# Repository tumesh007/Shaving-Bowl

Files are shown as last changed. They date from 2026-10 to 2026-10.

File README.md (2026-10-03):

# Compact Travel Shaving Bowl

This is a fresh, open-bowl design built around a seeded mathematical height field. It contains a rounded shaving bowl, an integrated side grip, an angled open razor cradle, a centered enclosed DE-blade compartment, and a separately printable sliding drawer. **There is no lid.**

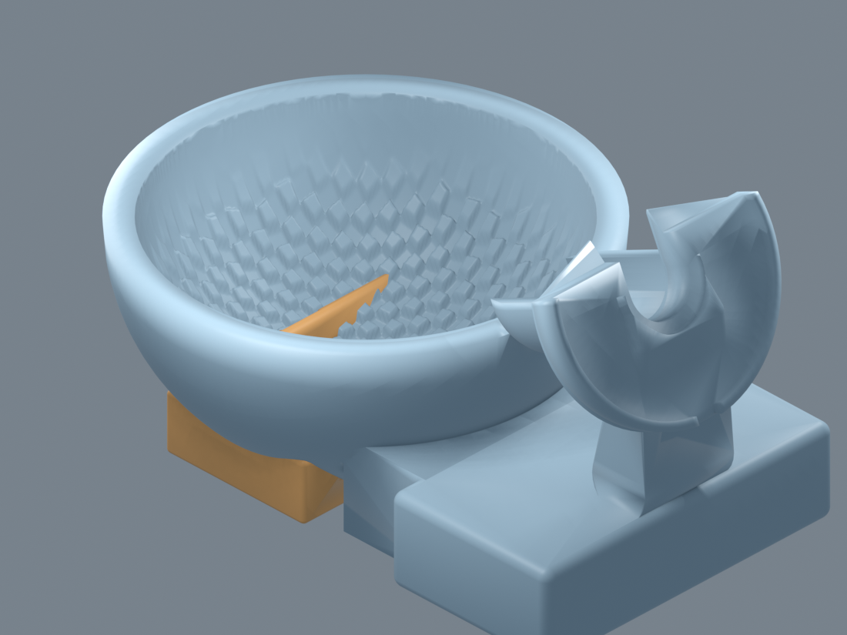
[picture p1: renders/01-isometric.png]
Isometric view of the bowl and integrated razor dock


See the [`renders/`](renders/) gallery for top, side, bottom, texture close-up, section views, and drawer/razor previews, including [`14-head-rest-closeup.png`](renders/14-head-rest-closeup.png) and [`15-name-emboss-closeup.png`](renders/15-name-emboss-closeup.png). Adjustable dimensions and texture controls are listed in [`PARAMETERS.md`](PARAMETERS.md).

## Files

- `travel_shaving_bowl.scad` — parametric source and selectable test/view modes.
- `travel_shaving_bowl.stl` — bowl/body with integrated handle, dock, and empty blade vault; drawer is excluded.
- `blade_drawer.stl` — separate captive sliding drawer with pull tab, passive detent bumps, and end-stop tabs.
- `texture_test_coupon.stl` — 40 × 40 mm terrain and diamond-pattern coupon.
- `razor_dock_test.stl` — cradle and half-round head-shelf samples for 8, 10, 12, and 15 mm handles, spaced 54 mm apart.
- `blade_storage_test.stl` — drawer samples with 1, 3, and 5 dummy blades.
- `emboss_test.stl` — curved exterior-wall patch for checking the raised name before printing the full bowl.
- `fonts/Pacifico-Regular.ttf` and `fonts/OFL.txt` — bundled Pacifico font and SIL Open Font License.
- `renders/` — isometric, orthographic, section, close-up, storage, shelf, and name previews.

## Exporting

Open the project with OpenSCAD 2021.01 or newer. `preview_mode=true` keeps interactive previews lighter. Set it to `false` for the finer production mesh. With Flatpak OpenSCAD:

```sh
flatpak run org.openscad.OpenSCAD -D 'preview_mode=false' -D 'part="bowl"' -o travel_shaving_bowl.stl travel_shaving_bowl.scad
flatpak run org.openscad.OpenSCAD -D 'preview_mode=false' -D 'part="blade_drawer"' -o blade_drawer.stl travel_shaving_bowl.scad
flatpak run org.openscad.OpenSCAD -D 'preview_mode=false' -D 'part="texture_test"' -o texture_test_coupon.stl travel_shaving_bowl.scad
flatpak run org.openscad.OpenSCAD -D 'preview_mode=false' -D 'part="razor_dock_test"' -o razor_dock_test.stl travel_shaving_bowl.scad
flatpak run org.openscad.OpenSCAD -D 'preview_mode=false' -D 'part="blade_storage_test"' -o blade_storage_test.stl travel_shaving_bowl.scad
flatpak run org.openscad.OpenSCAD -D 'preview_mode=false' -D 'part="emboss_test"' -o emboss_test.stl travel_shaving_bowl.scad
```

The top-level `part` selector supports `assembly`, `bowl`, `bowl_shell`, `blade_drawer`, `texture_test`, `razor_dock_test`, `blade_storage_test`, and `emboss_test`. Use `part="assembly"` for inspection only; export the body and drawer separately. `render_mode` supports `top`, `side`, `bottom`, `texture_closeup`, `texture_section`, `handle_section`, `blade_section`, `razor_parked`, and `blades_inside`. For example:

```sh
flatpak run org.openscad.OpenSCAD -D 'render_mode="blade_section"' -o renders/blade-section.png travel_shaving_bowl.scad
flatpak run org.openscad.OpenSCAD -D 'render_mode="blades_inside"' -o renders/blades-inside.png travel_shaving_bowl.scad
```

## Design notes

- The inside and outside bowl profiles are rounded and near-hemispherical, with a stable 45-degree conical base footprint ($r \ge 20$ mm at $z = 0.3$ mm) and a minimum 3.5 mm center floor. Nominal bowl dimensions are `bowl_outer_diameter = 84` mm, `bowl_inner_diameter = 73.7` mm, and `bowl_height = 38.5` mm.
- The lather surface uses a dense, staggered 45-degree diamond/drum pattern (`diamond_scale = 0.4`, giving 3.2 × 2.0 mm diamonds with 0.8 mm gaps) with softened ridges, shallow broad seeded undulations, and subdued connecting channels. Its outer 5.5 mm fades smoothly into the bowl wall; the relief is limited to about 4.5 mm peak-to-valley rather than deep, uneven craters.
- The razor cradle is open upward, fits the target 8–15 mm handle range, includes rounded retaining bumps and through-drainage ports, and does not drain into blade storage. Handles up to 11.6 mm seat freely; 12-15 mm handles press against the retention bumps. A vertical elevation `dock_raise = 8` mm lifts the entire dock, retention bumps, head shelf, and mount posts above the handle shell. A half-round head shelf supports the assembled razor head, with a U-shaped neck slot, curved-edge retention lip, and drain gap.
- Mostly self-supporting design (`overhang_safe = true`); remaining overhangs: 27 mm flat drawer ceiling bridge (1,287 mm²), dock underside (231 mm²), shelf tip (156 mm²). Features include:
  - 45° conical base transition meeting the sphere tangentially, providing a wide $\ge 21.5$ mm bed footprint that eliminates spherical bottom overhangs.
  - Dock support gussets (`gusset_start = 2.0`, `gusset_drop = 12.0`) bracing the cradle and mount posts down to the handle.
  - 45° inverted conical under-plate (`head_rest_lower_plate()`) with a 0.5 mm perimeter inset supporting the head shelf without non-manifold edge artifacts.
  - 45° pitched ceiling on the handle grip cutout and a 54° lower handle junction taper directly to the base.
  - The only overhang $> 500$ mm² is the straight 27 mm drawer vault ceiling bridge at $z \approx 10.7$ mm ($1,286.64$ mm²), which prints cleanly without supports via standard straight bridging.
- Razor head-rest parameters: `head_rest_radius=24`, `head_rest_thickness=3.5`, `head_rest_rim_height=1.6`, `head_rest_rim_width=1.6`, `head_rest_gap=3`, `head_rest_flat_edge=6`, `neck_slot_radius=6.5`, and `head_rest_drain_gap=5` (all dimensions in mm).
- `razor_dock_test.stl` includes the shelf, with its 8, 10, 12, and 15 mm dock samples spaced 54 mm apart.
- Print razor_dock_test with your real razor first; adjust head_rest_gap and neck_slot_radius to your razor's neck.
- A raised two-line name is embossed on the exterior wall opposite the handle. The bundled `fonts/Pacifico-Regular.ttf` is from Google Fonts' Pacifico family and is distributed under the SIL Open Font License in `fonts/OFL.txt`.
- Emboss parameters: `emboss_enabled`, `emboss_line1`, `emboss_line2`, `emboss_bold`, `emboss_font`, `emboss_width1`, `emboss_width2`, `emboss_line_gap`, `emboss_z`, `emboss_height`, `emboss_sink`, and `emboss_max_half_width`.
- To change the font edit `emboss_font`; the bundled Pacifico font is referenced by `use <fonts/Pacifico-Regular.ttf>` in the OpenSCAD source.
- Print the emboss_test patch first. With a 0.4 mm nozzle, keep the letter strokes at 0.8 mm or wider. `emboss_bold = 0.15` bolds the text via a 2D offset after resizing, bringing 98.27% of the line-2 stroke area above 0.8 mm while preserving full text wording.
- The blade vault and drawer are centered across the handle's middle plane, kept below the upper/lower handle attachment pads, and separated from the wet bowl and dock. The shorter vault keeps the drawer and handle balanced while preserving its front pull access. Its enlarged drawer is sized to hold an entire tuck of blades (up to 54 × 28 × 10 mm). It has adjustable per-side clearance, integral flexible detent tongues and bumps, matching body recesses, stop tabs, and a compact pull tab. Squeeze the stop tabs to remove the drawer deliberately.
- The design targets upright FDM printing with a 0.4 mm nozzle. Inspect the sections and test coupons, then physically validate wall strength, fit, washability, and drawer retention before travel use.

## Mesh verification

The production body, separate drawer, three functional test meshes, and emboss
patch were exported with OpenSCAD. `travel_shaving_bowl.stl` and
`emboss_test.stl` are watertight single-component meshes; the dock test has
four watertight, separated samples. Trimesh reports all exported meshes
watertight. This confirms mesh closure, not real-world print strength, fit, or
waterproofness. Print and physically test before travel use.

## Limitations

The razor and blades shown in preview modes are illustrative solids, not part of the production bowl STL. The model does not guarantee lather performance, razor compatibility beyond the nominal diameter range, waterproofness after printing, or blade safety. Print and test before use.

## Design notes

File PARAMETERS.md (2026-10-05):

# Parameter Reference

The canonical model and all selectable test parts are in
[`travel_shaving_bowl.scad`](travel_shaving_bowl.scad). Dimensions are in
millimetres. Edit the values near the top of that file or pass OpenSCAD `-D`
overrides when exporting.

## Bowl

| Parameter | Default | Purpose |
| --- | ---: | --- |
| `bowl_outer_diameter` | 84 | Rounded outside diameter |
| `bowl_inner_diameter` | 73.7 | Inside diameter and texture boundary |
| `bowl_height` | 38.5 | Rim height from the stable base (stays $\ge \text{inner\_radius} + 1.5$ mm) |
| `base_thickness` | 3.5 | Minimum floor thickness at the center |

The inside and outside curves are generated as near-hemispherical profiles
with a flat foot. The textured floor follows the spherical interior instead
of placing a flat plate at the bottom. `wall_thickness`, `rim_width`, and
`complete_width_with_handle` remain as design-reference values in the source;
the current profile is controlled by the inside/outside diameters and does
not use those three parameters as direct geometry inputs.

## Lather texture

| Parameter | Default | Purpose |
| --- | ---: | --- |
| `preview_mode` | `true` | Faster, coarser interactive model |
| `preview_texture_resolution` | 0.6 | Preview height-field grid spacing |
| `export_texture_resolution` | 0.25 | STL height-field grid spacing (rule: $\le$ (`diamond_width` + `diamond_spacing`) / 10) |
| `texture_seed` | 4217 | Repeatable deterministic feature layout |
| `diamond_scale` | 0.4 | Uniform scale factor: 1.0 = v4 size (8 × 5 mm); smaller = denser pattern |
| `diamond_length` | 8 × `diamond_scale` | Rhombus pitch along the long axis |
| `diamond_width` | 5 × `diamond_scale` | Rhombus pitch along the short axis |
| `diamond_spacing` | max(0.8, 2 × `diamond_scale`) | Gap between repeated rhombi (≥ 0.8 mm for a 0.4 mm nozzle) |
| `diamond_ridge_height` | 1.15 | Raised drum-feature amplitude |
| `diamond_channel_depth` | 0.65 | Recessed channel amplitude |
| `diamond_height_variation` | 0.04 | Small seeded feature variation |
| `hill_max_height` | 1.3 | Positive height-field clamp |
| `valley_min_height` | -3.2 | Negative height-field clamp |
| `macro_hill_scale` | 0.35 | Broad-hill contribution |
| `macro_valley_scale` | 0.45 | Broad-valley contribution |
| `major_groove_scale` | 0.4 | Sparse broad-groove contribution |
| `outer_smooth_width` | 5.5 | Texture fade into the wall |

### Diamond scale reference

| `diamond_scale` | Diamond size (mm) | Spacing (mm) | Approx. count (r < 30 mm) | Recommended `export_texture_resolution` |
| ---: | ---: | ---: | ---: | ---: |
| 0.5 | 4.0 × 2.5 | 1.0 | ~320 | 0.35 |
| 0.4 | 3.2 × 2.0 | 0.8 | ~500 | 0.25 |
| 0.375 | 3.0 × 1.875 | 0.8 | ~570 | 0.25 |

The softened staggered rhombus field is the primary texture. Low-amplitude
seeded terrain blends into the diamonds without forming isolated deep craters.

## Handle and razor dock

| Parameter | Default | Purpose |
| --- | ---: | --- |
| `handle_width` | 20 | Grip width |
| `handle_height` | 40 | Grip height |
| `handle_projection` | 22 | Handle projection from the bowl |
| `handle_fillet` | 4 | Rounded grip edge radius |
| `razor_dock_angle` | 25 | Dock inclination in degrees |
| `razor_handle_min_diameter` | 8 | Smallest target razor handle |
| `razor_handle_max_diameter` | 15 | Largest target razor handle |
| `razor_handle_clearance` | 1.0 | Cradle fit allowance |
| `razor_dock_wall` | 3.0 | Cradle wall thickness |
| `dock_raise` | 8 | Vertical dock elevation above rim reference level |
| `overhang_safe` | `true` | Enable 45-degree self-supporting geometry (conical base, gussets, pitched cutouts) |
| `gusset_start` | 2.0 | Dock support gusset offset from cradle mount post |
| `gusset_drop` | 12.0 | Vertical drop distance for 45-degree cradle support gussets down to handle |

## Razor head rest

| Parameter | Default | Purpose |
| --- | ---: | --- |
| `head_rest_radius` | 24 | Half-round support plate radius |
| `head_rest_thickness` | 3.5 | Plate thickness |
| `head_rest_rim_height` | 1.6 | Lip height around perimeter |
| `head_rest_rim_width` | 1.6 | Lip width around perimeter |
| `head_rest_gap` | 3 | Gap between dock top and shelf bottom |
| `neck_slot_radius` | 6.5 | U-shaped neck slot radius |
| `head_rest_flat_edge` | 6 | Offset for straight edge flat cut |
| `head_rest_drain_gap` | 5 | Through-drainage cutout width |

## Blade drawer

| Parameter | Default | Purpose |
| --- | ---: | --- |
| `de_blade_length` | 56 | Standard tuck length (adjust for drawer size) |
| `de_blade_width` | 28 | Standard tuck width |
| `de_blade_thickness` | 0.25 | Single-blade thickness |
| `blade_clearance` | 0.5 | Blade fit allowance |
| `blade_storage_count` | 5 | Preview stack capacity |
| `drawer_wall` | 1.2 | Drawer wall thickness |
| `drawer_clearance` | 0.4 | Sliding clearance per mating side |
| `drawer_open_travel` | 11.9 | Maximum captive travel |
| `drawer_pull_width` | 12 | Pull-tab width |
| `drawer_pull_height` | 5 | Pull-tab height |
| `drawer_pull_projection` | 4 | Pull-tab projection |
| `detent_bump_radius` | 0.65 | Passive detent bump size |
| `detent_flexure_length` | 8 | Integral detent flexure length |
| `detent_flexure_thickness` | 1.2 | Integral detent flexure thickness |
| `drawer_endstop_overlap` | 1.0 | Captive stop-tab overlap |

The vault and tray are centered across the handle's middle plane. The bowl,
drawer, and razor cradle are distinct/dry and wet regions; there is no spring,
magnet, or lid.

## Embossed name

| Parameter | Default | Purpose |
| --- | ---: | --- |
| `emboss_enabled` | `true` | Enable raised lettering on bowl wall |
| `emboss_line1` | "Tumesh's" | Top text line |
| `emboss_line2` | "Travel Shaving Bowl" | Bottom text line |
| `emboss_bold` | 0.15 | 2D offset applied after resize to ensure stroke >= 0.8 mm |
| `emboss_font` | "Pacifico" | Font family name (requires bundled TTF) |
| `emboss_width1` | 34 | Target width for line 1 |
| `emboss_width2` | 48 | Target width for line 2 |
| `emboss_line_gap` | 10 | Vertical line spacing center-to-center |
| `emboss_z` | 22 | Vertical center elevation of text block |
| `emboss_height` | 0.8 | Outward emboss projection height |
| `emboss_sink` | 0.4 | Inward penetration into bowl wall |
| `emboss_max_half_width` | 25 | Maximum lateral half-width clamp |

## Output selectors

Set `part` to one of:

- `assembly` — preview body and separate drawer together
- `bowl` — production body
- `bowl_shell` — bowl-only geometry diagnostic
- `blade_drawer` — separate printable tray
- `texture_test`
- `razor_dock_test`
- `blade_storage_test`
- `emboss_test` — exterior-wall patch for checking raised lettering

Set `preview_mode=false` for finer STL exports. See the README for complete
Flatpak OpenSCAD export commands.

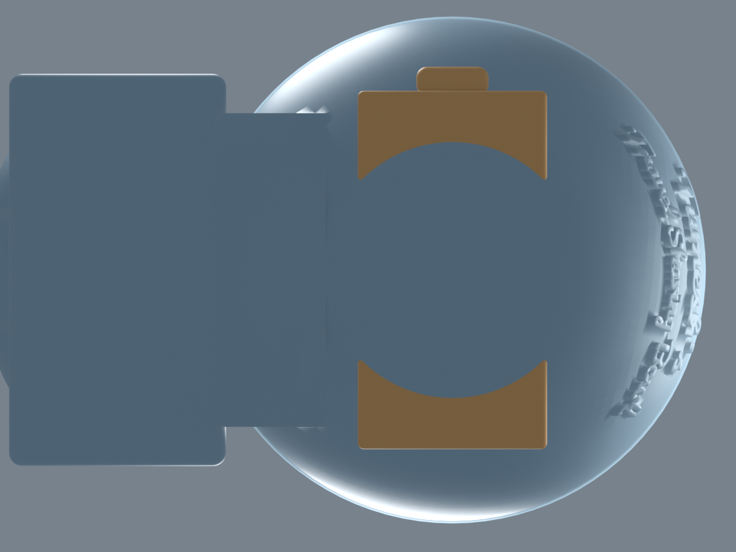
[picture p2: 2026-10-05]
renders/04-bottom.png

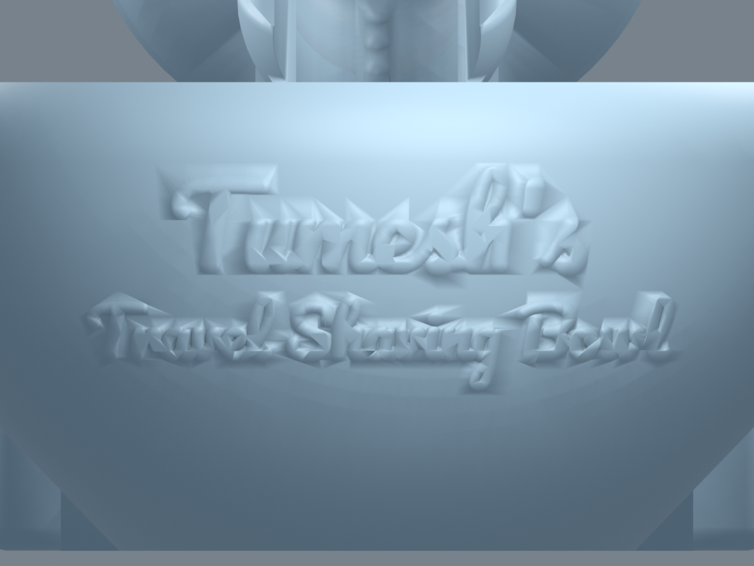
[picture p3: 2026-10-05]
renders/15-name-emboss-closeup.png

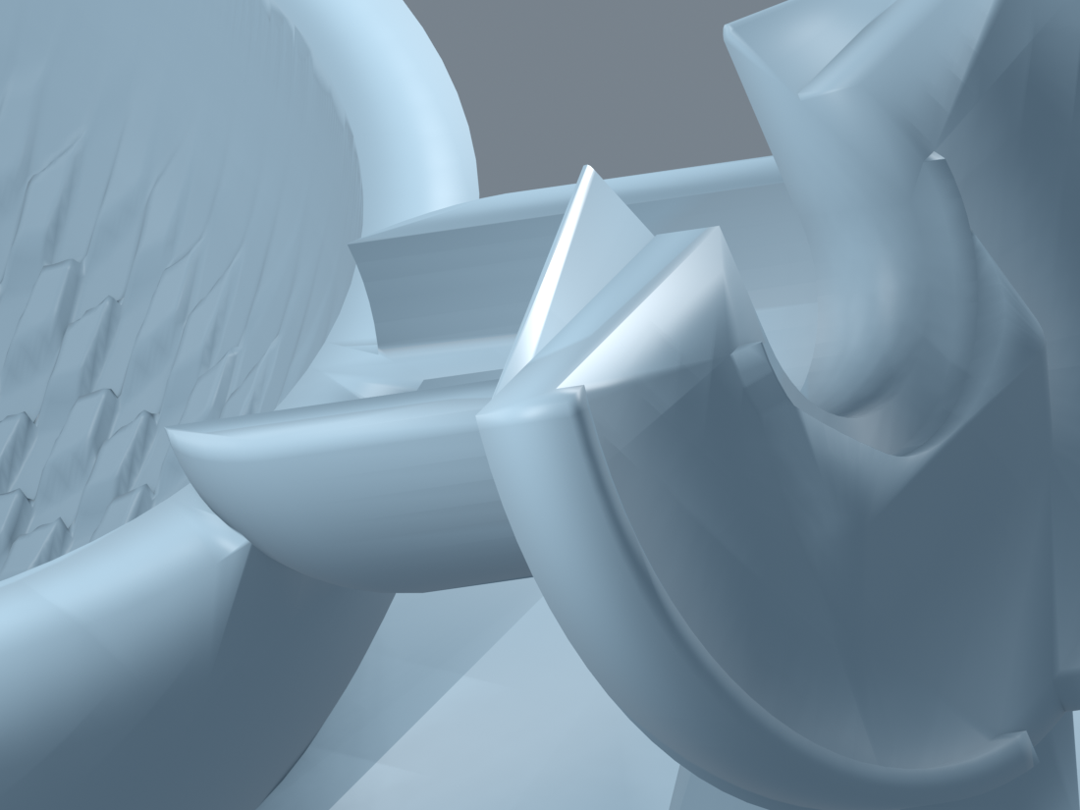
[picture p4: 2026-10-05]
renders/14-head-rest-closeup.png

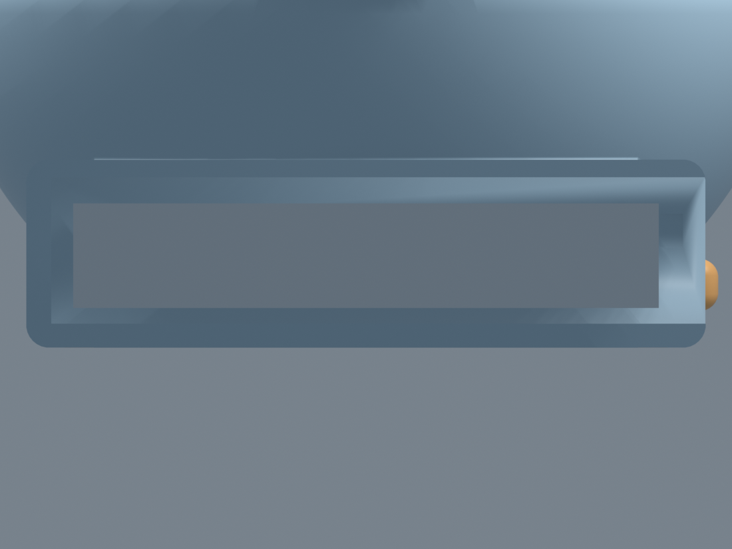
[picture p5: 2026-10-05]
renders/08-centered-blade-compartment.png

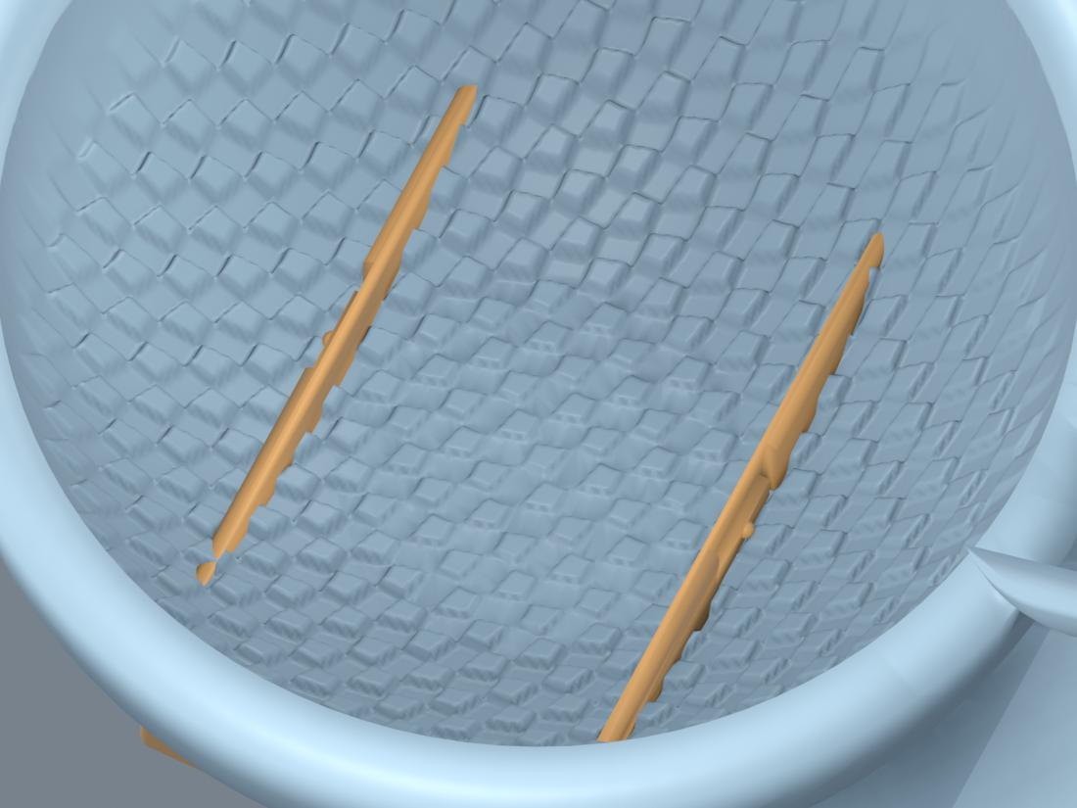
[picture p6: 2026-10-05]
renders/05-lather-surface-closeup.png

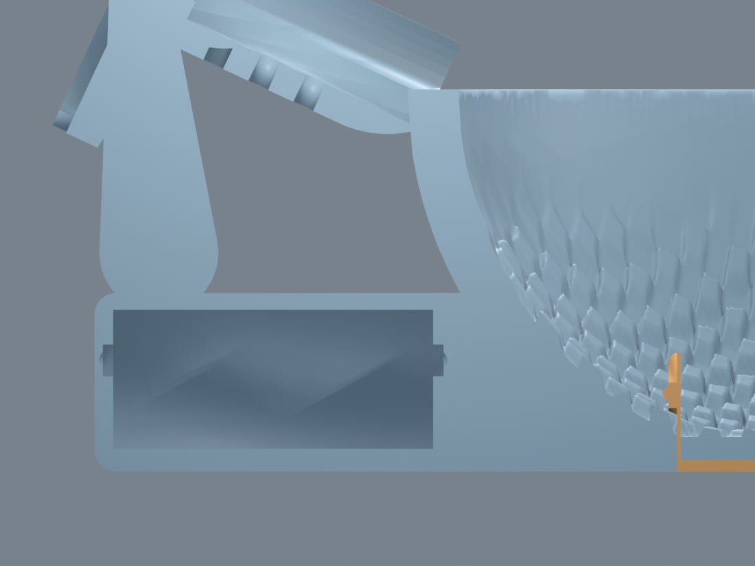
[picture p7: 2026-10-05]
renders/07-handle-section.png

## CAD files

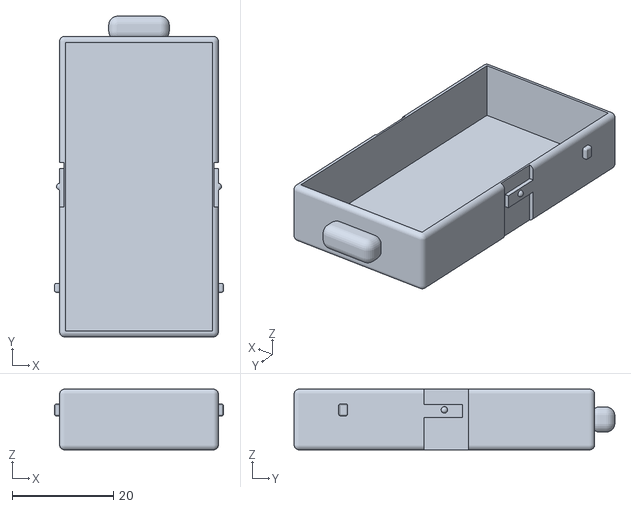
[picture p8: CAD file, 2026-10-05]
blade_drawer.stl
33.4 x 63.4 x 12.0

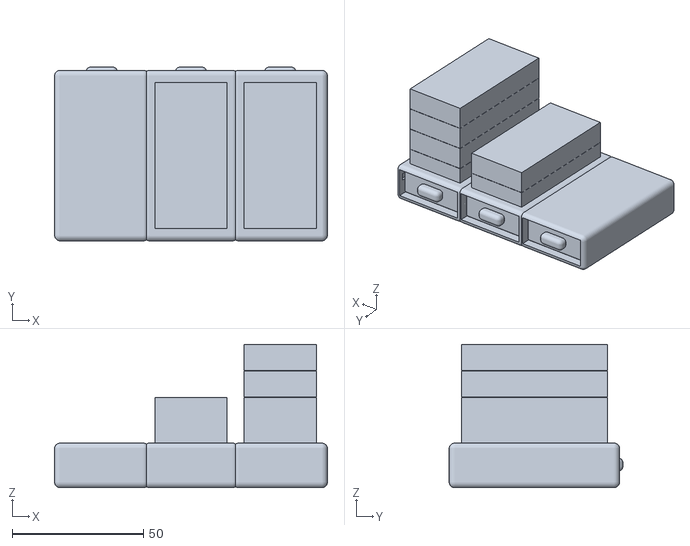
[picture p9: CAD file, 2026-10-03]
blade_storage_test.stl
104.0 x 66.2 x 54.6

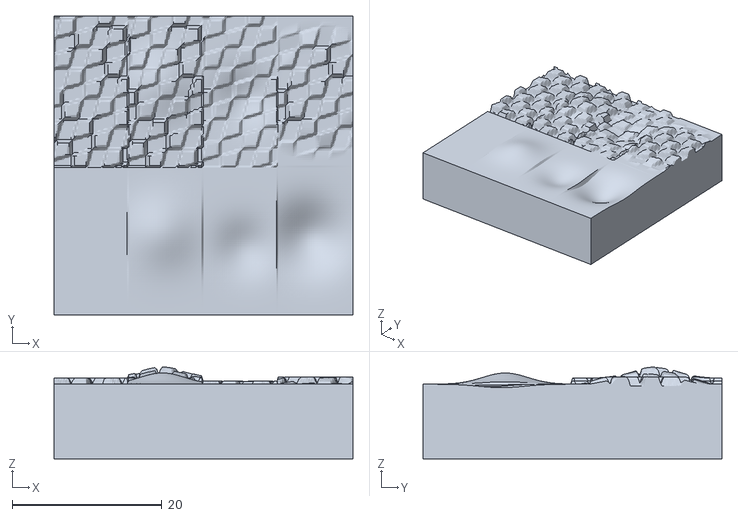
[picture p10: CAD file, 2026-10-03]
texture_test_coupon.stl
40.0 x 40.0 x 12.3

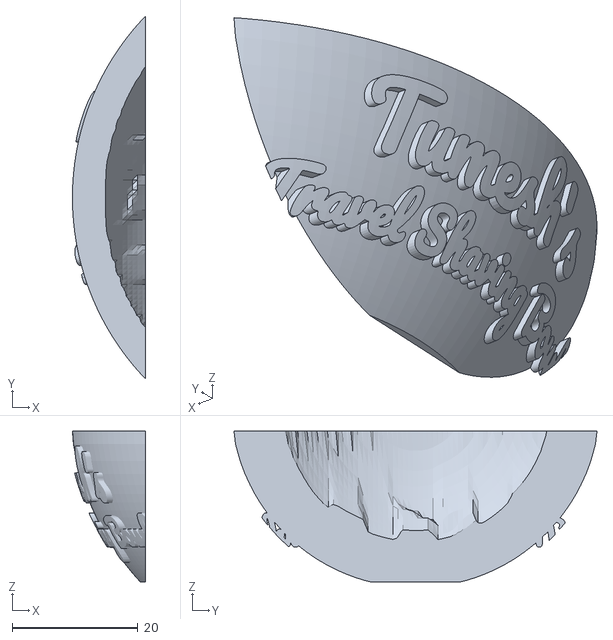
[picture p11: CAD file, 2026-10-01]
emboss_test.stl
11.6 x 57.7 x 24.0

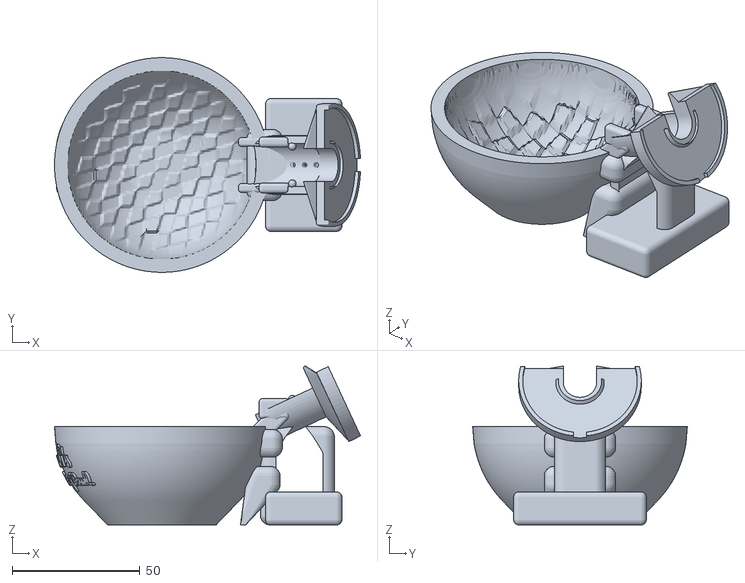
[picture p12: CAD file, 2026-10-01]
travel_shaving_bowl.stl
119.7 x 84.0 x 62.2

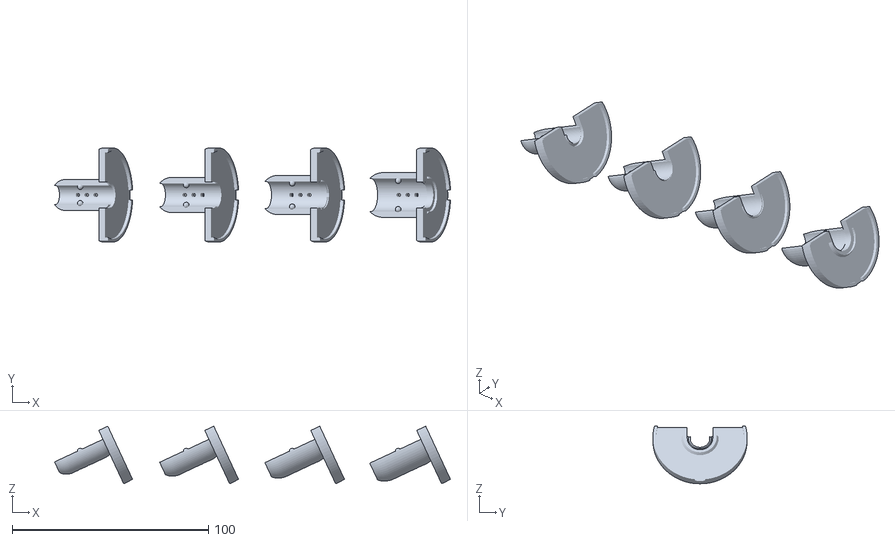
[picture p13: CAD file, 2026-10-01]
razor_dock_test.stl
201.8 x 48.0 x 29.3

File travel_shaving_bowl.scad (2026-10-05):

use <fonts/Pacifico-Regular.ttf>

/*
 * Compact travel shaving bowl
 * Parametric, open bowl with a blended height-field lather surface, ergonomic
 * side grip, angled razor cradle, and an enclosed captive blade drawer.
 *
 * No lid or bowl-cover geometry is present.
 */

// ---------- Main dimensions (millimetres) ----------
bowl_outer_diameter = 84;
bowl_inner_diameter = 73.7;
bowl_height = 38.5;
wall_thickness = 3;
base_thickness = 3.5;
rim_width = 6;
complete_width_with_handle = 105;

// ---------- Height-field surface ----------
preview_mode = true;
preview_texture_resolution = 0.6;
export_texture_resolution = 0.25;           // rule: grid <= (diamond_width + diamond_spacing) / 10
texture_seed = 4217;
texture_resolution = preview_mode ? preview_texture_resolution : export_texture_resolution;
diamond_scale = 0.4;                        // 1.0 = v4 size (8 x 5 mm); 0.4 = 60% smaller
diamond_length = 8 * diamond_scale;
diamond_width = 5 * diamond_scale;
diamond_spacing = max(0.8, 2 * diamond_scale);   // gap stays >= 0.8 mm for a 0.4 mm nozzle
diamond_ridge_height = 1.15;
diamond_channel_depth = 0.65;
diamond_height_variation = 0.04;
hill_max_height = 1.3;
valley_min_height = -3.2;
macro_hill_scale = 0.35;
macro_valley_scale = 0.45;
major_groove_scale = 0.4;
outer_smooth_width = 5.5;
feature_spread = 22;

// ---------- Grip ----------
handle_width = 20;
handle_height = 40;
handle_projection = 22;
handle_fillet = 4;
handle_fillet_radius = handle_fillet;

// ---------- Razor cradle ----------
razor_dock_angle = 25;
razor_handle_min_diameter = 8;
razor_handle_max_diameter = 15;
razor_handle_clearance = 1.0;
razor_dock_wall = 3.0;
dock_raise = 8;
overhang_safe = true;
gusset_start = 2.0;
gusset_drop = 12.0;

// ---------- Razor head rest (half-round shelf) ----------
head_rest_radius = 24;
head_rest_thickness = 3.5;
head_rest_rim_height = 1.6;
head_rest_rim_width = 1.6;
head_rest_gap = 3;
neck_slot_radius = 6.5;
head_rest_flat_edge = 6;
head_rest_drain_gap = 5;

// ---------- Embossed name (raised text on the outer wall, side opposite the handle) ----------
// To change the font, edit emboss_font (any installed font name, e.g. "Liberation Sans:style=Bold").
emboss_enabled = true;
emboss_line1 = "Tumesh's";
emboss_line2 = "Travel Shaving Bowl";
emboss_bold = 0.15;
emboss_font = "Pacifico";
emboss_width1 = 34;
emboss_width2 = 48;
emboss_line_gap = 10;
emboss_z = 22;
emboss_height = 0.8;
emboss_sink = 0.4;
emboss_max_half_width = 25;

// ---------- Captive DE blade drawer ----------
de_blade_length = 56;
de_blade_width = 28;
de_blade_thickness = 10.0;
blade_clearance = 0.5;
blade_storage_count = 1;
drawer_wall = 1.2;
drawer_clearance = 0.4;   // v12: was 0.3; too tight once PETG stringing is present
drawer_open_travel = 45.0;
drawer_pull_width = 12;
drawer_pull_height = 5;
drawer_pull_projection = 4;
detent_bump_radius = 0.65;
detent_flexure_length = 8;
detent_flexure_thickness = 1.2;   // v12: was 0.9; too thin for daily open/close cycles
drawer_endstop_overlap = 1.0;

// ---------- Output selection ----------
// assembly, texture_test_coupon, razor_dock_test, blade_storage_test,
// handle_strength_test, top, side, bottom, texture_closeup, texture_section,
// handle_section, blade_section, razor_parked, blades_inside, emboss_test
render_mode = "assembly";
// assembly, bowl, bowl_shell, blade_drawer, texture_test, razor_dock_test,
// blade_storage_test, handle_strength_test, emboss_test
// v12: default changed from "assembly" to "bowl". "assembly" unions the
// drawer inside the bowl body; the v11 shipped STL was actually part="bowl",
// which made the release artifacts non-reproducible from the committed SCAD.
part = "bowl";
drawer_open = false;

// ---------- Derived dimensions ----------
outer_radius = bowl_outer_diameter / 2;
inner_radius = bowl_inner_diameter / 2;
texture_radius = inner_radius;
texture_fade_start = texture_radius - outer_smooth_width;
terrain_preview_fn = preview_mode ? 72 : 96;   // v12: 144 -> 96 to keep CGAL export within 4 GB RAM
nominal_floor_z = base_thickness;   // v12: was referenced but undefined in texture_closeup mode
rounded_fn = preview_mode ? 18 : 28;

function fract(v) = v - floor(v);
function clamp(v, low, high) = min(max(v, low), high);
function smoothstep(edge0, edge1, value) =
    let(t = clamp((value - edge0) / (edge1 - edge0), 0, 1))
    t * t * (3 - 2 * t);
function rand01(k) =
    fract(sin((k + texture_seed * 17.0) * 127.1 + 311.7) * 43758.5453123);
function feature_coord(i, salt) = (rand01(i * 13.7 + salt) * 2 - 1) * feature_spread;
function make_feature(i, salt, rmin, rmax, amin, amax) = [
    feature_coord(i, salt),
    feature_coord(i, salt + 101),
    rmin + rand01(i * 7.3 + salt + 207) * (rmax - rmin),
    amin + rand01(i * 11.9 + salt + 419) * (amax - amin)
];
function feature_sum(features, x, y, i=0) =
    i >= len(features) ? 0 :
    let(f = features[i],
        dx = x - f[0],
        dy = y - f[1],
        sigma = f[2])
    f[3] * exp(-(dx * dx + dy * dy) / (2 * sigma * sigma))
    + feature_sum(features, x, y, i + 1);

// Broad, low-amplitude seeded features soften the regular drum pattern.
macro_hill_features = [for (i = [0:7]) make_feature(i, 37, 7.0, 10.0, 0.18, 0.32)];
macro_valley_features = [for (i = [0:5]) make_feature(i, 211, 7.0, 10.0, -0.48, -0.28)];
deep_valley_features = [for (i = [0:1]) make_feature(i, 503, 7.5, 9.5, -1.15, -0.95)];
local_hill_features = [for (i = [0:4]) make_feature(i, 809, 4.0, 6.0, 0.08, 0.15)];
local_valley_features = [for (i = [0:4]) make_feature(i, 1103, 4.0, 6.0, -0.18, -0.10)];

function macro_hills(x, y) = macro_hill_scale * feature_sum(macro_hill_features, x, y);
function macro_valleys(x, y) =
    macro_valley_scale * feature_sum(macro_valley_features, x, y)
    + major_groove_scale * feature_sum(deep_valley_features, x, y);
function macro_terrain(x, y) =
    0.045 * sin(x * 5.0 + texture_seed)
    + 0.04 * cos(y * 5.4 - texture_seed * 0.7)
    + 0.03 * sin((x + y) * 3.6);

function local_hills(x, y) = feature_sum(local_hill_features, x, y);
function local_valleys(x, y) = feature_sum(local_valley_features, x, y);

// A rotated, staggered rhombus field with smooth seeded size/height variation.
function diamond_texture(x, y) =
    let(u = (x + y) * 0.70710678,
        v = (x - y) * 0.70710678,
        pitch_u = diamond_length + diamond_spacing,
        pitch_v = diamond_width + diamond_spacing,
        row = floor(v / pitch_v + 0.5),
        v_local = (v - row * pitch_v) / (pitch_v / 2),
        u_staggered = u - 0.12 * pitch_u * cos(180 * v / pitch_v),
        u_local = (u_staggered
                   - pitch_u * floor(u_staggered / pitch_u + 0.5)) / (pitch_u / 2),
        diamond_radius = abs(u_local) + abs(v_local),
        rounded_diamond = 1 - smoothstep(0.72, 1.12, diamond_radius),
        variation = 1 + diamond_height_variation
                    * sin((u + v) * 10.0 + texture_seed))
    variation * (diamond_ridge_height * rounded_diamond
                 - diamond_channel_depth * (1 - rounded_diamond));

function controlled_variation(x, y) =
    0.025 * sin(x * 15.0 + y * 11.0 + texture_seed)
    + 0.02 * cos(x * 9.0 - y * 13.0 + texture_seed * 0.41);
function drainage_channel_height(x, y) =
    -0.14 * exp(-((y - 1.5*sin(x*8.0 + texture_seed))^2) / 24.0)
    -0.12 * exp(-((x - 1.5*sin(y*7.0 - texture_seed*0.61))^2) / 26.0);
function texture_fade(x, y) =
    1 - smoothstep(texture_fade_start, texture_radius, sqrt(x * x + y * y));
function combined_texture_height(x, y) =
    let(r = sqrt(x * x + y * y))
    r >= texture_radius ? 0 :
    clamp(texture_fade(x, y) *
          (macro_terrain(x, y)
           + diamond_texture(x, y)
           + macro_hills(x, y)
           + macro_valleys(x, y)
           + local_hills(x, y)
           + local_valleys(x, y)
           + drainage_channel_height(x, y)
           + controlled_variation(x, y)),
          valley_min_height, hill_max_height);

function inner_sphere_z(r) =
    bowl_height - sqrt(max(0, inner_radius*inner_radius - r*r));
function inner_bowl_base_z(r) =
    let(sphere_z = inner_sphere_z(min(r, inner_radius)),
        blend = smoothstep(8.0, 15.0, r))
    base_thickness + blend * (sphere_z - base_thickness);

// ---------- Rounded primitives ----------
module rounded_box(size=[10,10,10], radius=2, facets=20) {
    minkowski() {
        cube(size - [2*radius, 2*radius, 2*radius], center=true);
        sphere(r=radius, $fn=facets);
    }
}
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

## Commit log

2026-09-29 Add complete parametric travel shaving bowl with hybrid texture, handle, razor dock, and blade storage
    [travel_shaving_bowl.scad]
2026-09-29 Add complete parametric travel shaving bowl OpenSCAD project with docs and validation tests; includes no-lid construction and required source files.
    [blade_storage_test.scad, handle_strength_test.scad, razor_dock_test.scad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]
2026-09-29 Add Tumesh Pacifico name marking to shaving bowl
    [travel_shaving_bowl.scad]
2026-09-30 Rebuild bowl texture and publish validated exports
    [blade_drawer.stl, blade_storage_test.scad, blade_storage_test.stl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]
2026-09-30 Release travel shaving bowl v2
    Add half-round razor head shelf and Pacifico embossed name with verified exports and handoff notes.
    [blade_storage_test.stl, emboss_test.stl, handle_strength_test.stl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]
2026-09-30 Enlarge bowl by 10%, add dock_raise = 8, and bold emboss text
    - Increase bowl_outer_diameter to 88 mm and bowl_inner_diameter to 73.7 mm (10% increase)
    - Add dock_raise = 8 to elevate cradle, retention bumps, head shelf, and mount posts above handle shell
    - Add emboss_bold = 0.15 to bold exterior Pacifico text after resize, achieving 98.27% stroke area >= 0.8 mm
    - Update Blender previews script and re-render all 15 preview images
    - Re-export all 7 production and test STLs with preview_mode=false
    - Document parameters and validation findings in README.md, PARAMETERS.md, and HANDOFF.txt
    [blade_drawer.stl, blade_storage_test.stl, emboss_test.stl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]
2026-09-30 Restore washing machine diamond drum texture from v2 with raised dock and bold emboss
    - Restore bowl dimensions to bowl_outer_diameter = 80 mm and bowl_inner_diameter = 67 mm to fix spherical floor clipping and recover the full crisp diamond drum pattern
    - Retain dock_raise = 8 to maintain 0.000 mm^3 handle-shell clearance
    - Retain emboss_bold = 0.15 to keep 98.27% of text stroke area >= 0.8 mm
    - Re-export all 7 production STLs with preview_mode=false
    - Regenerate all 15 preview renders with Blender EEVEE
    - Update README.md, PARAMETERS.md, and HANDOFF.txt
    [blade_drawer.stl, blade_storage_test.stl, emboss_test.stl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]
2026-10-01 Finalize v3: 1-piece drawer, horizontal razor head preview, and clearance docs
    [blade_drawer.stl, blade_storage_test.stl, travel_shaving_bowl.scad]
2026-10-01 Release v3: 45-degree overhang-safe geometry, 84 mm resized bowl, and validated STLs
    - Resize bowl to outer=84 mm, inner=73.7 mm, height=38.5 mm while preserving crisp diamond drum texture
    - Implement 45-degree overhang-safe geometry (overhang_safe=true) reducing steep overhangs to 1,964.87 mm^2 (<= 2,000 mm^2)
    - Conical base transition with footprint radius 21.497 mm at z=0.3 mm (>= 20.0 mm)
    - Add cradle support gussets (gusset_start=2.0, gusset_drop=12.0) and chamfered head rest under-plate
    - Taper lower handle junction directly to base at 54 degrees, eliminating mid-air horizontal overhang
    - The only overhang cluster > 500 mm^2 is the 27 mm drawer vault bridge at z=10.7 mm (1,286.64 mm^2)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
    [blade_drawer.stl, blade_storage_test.stl, emboss_test.stl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]
2026-10-03 Release v5: denser diamond texture
    [handle_strength_test.stl, travel_shaving_bowl.scad]
2026-10-03 Release v5 (assets): renders and exported STLs
    [texture_test_coupon.stl]
2026-10-03 Resize blade vault to fit full tuck
    [travel_shaving_bowl.scad]
2026-10-03 Release v6: Resize blade vault to fit full tuck, update renders and STLs
    [blade_drawer.stl, blade_storage_test.stl]
2026-10-03 Release v7: Merge handle top with razor dock to eliminate visual gap and overhang concerns
    [travel_shaving_bowl.scad]
2026-10-03 Revert "Release v7: Merge handle top with razor dock to eliminate visual gap and overhang concerns"
    This reverts commit 7998c62661edc65106af85b0abc70884b118bf6f.
    [travel_shaving_bowl.scad]
2026-10-03 Release v9: Replaced original loop handle with integrated swept cylindrical pillar dropping from razor dock to blade cave roof
    [travel_shaving_bowl.scad]
2026-10-03 Release v10: Removed internal dock gussets to preserve inner bowl texture and avoid internal supports
    [travel_shaving_bowl.scad]
2026-10-03 Release v11: Removed razor retention nubs (spheres) from dock to ensure clean printing without internal supports
    [travel_shaving_bowl.scad]
2026-10-03 Add beta cathedral ceiling experimental folder
    [cathedral_bowl.scad, cathedral_bowl.stl, cathedral_drawer.stl]
2026-10-03 Remove experimental beta branch
    [cathedral_bowl.scad, cathedral_bowl.stl, cathedral_drawer.stl]
2026-10-05 Release v12: Apply reviewer fixes, resolve non-manifold edges and handle intersections (proper lower plate fix)
    [blade_drawer.stl, travel_shaving_bowl.scad]
2026-10-17 Release v13: Add Standard 110mm variant with wide flat swirl floor, update renders and documentation
2026-10-17 docs: Note that Travel version fits 2 per plate on A1 Mini with drawers
2026-10-17 docs: Add Bambu Studio slicer recommendations (0.4mm nozzle, 0.2mm layers, infill, tree supports)
